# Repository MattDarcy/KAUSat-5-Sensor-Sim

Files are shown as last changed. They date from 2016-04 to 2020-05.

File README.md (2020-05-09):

# KAUSAT-5 Sensor Simulator

**Summary**

MATLAB/Embedded C software for the ADCS sensor simulator for KAUSAT-5, a 3U CubeSat developed at Korea Aerospace University's [Space Systems Research Laboratory](https://www.facebook.com/ssrlmm/). This was the main work of my 2014-2015 Fulbright grant to South Korea. The complete system was capable of delivering real-time simulated sensor data from the MATLAB-STK interface via ATMega128 to KAUSAT-5's ADCS board for on-the-ground debugging purposes.

Simulated sensors included 5x sun, x-y-x mag, and x-y-z gyro. 
Data transfer protocols included UART, SPI, I2C.

**>>> [Check Out On YouTube](https://www.youtube.com/watch?v=KioAFfxGl1A) <<<**

Out Front of KAU (https://www.youtube.com/watch?v=KioAFfxGl1A)

Running simulation of KAUSAT-5 (https://www.youtube.com/watch?v=KioAFfxGl1A)

**Hardware**

ATMega128 (1x as simulator unit, 1x as MASTER for simulator verification)  
LTC2630 Digital-Analog Converter (13x)  
Simulator PCB (1x) created in Altium Designer v13.2
See documentation folder for details

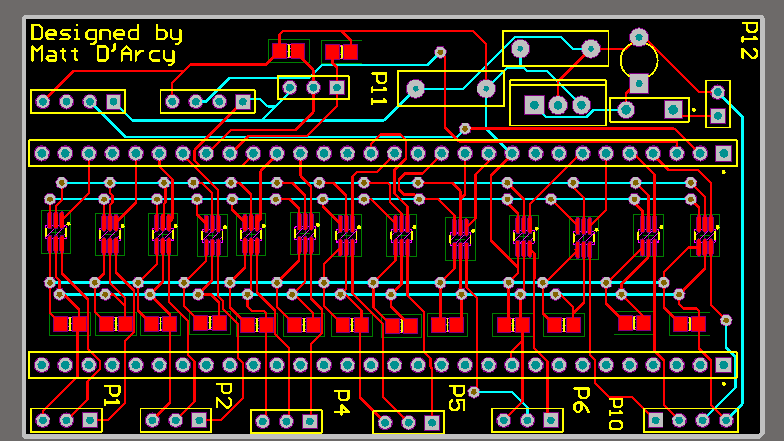
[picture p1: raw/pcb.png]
Simulator PCB

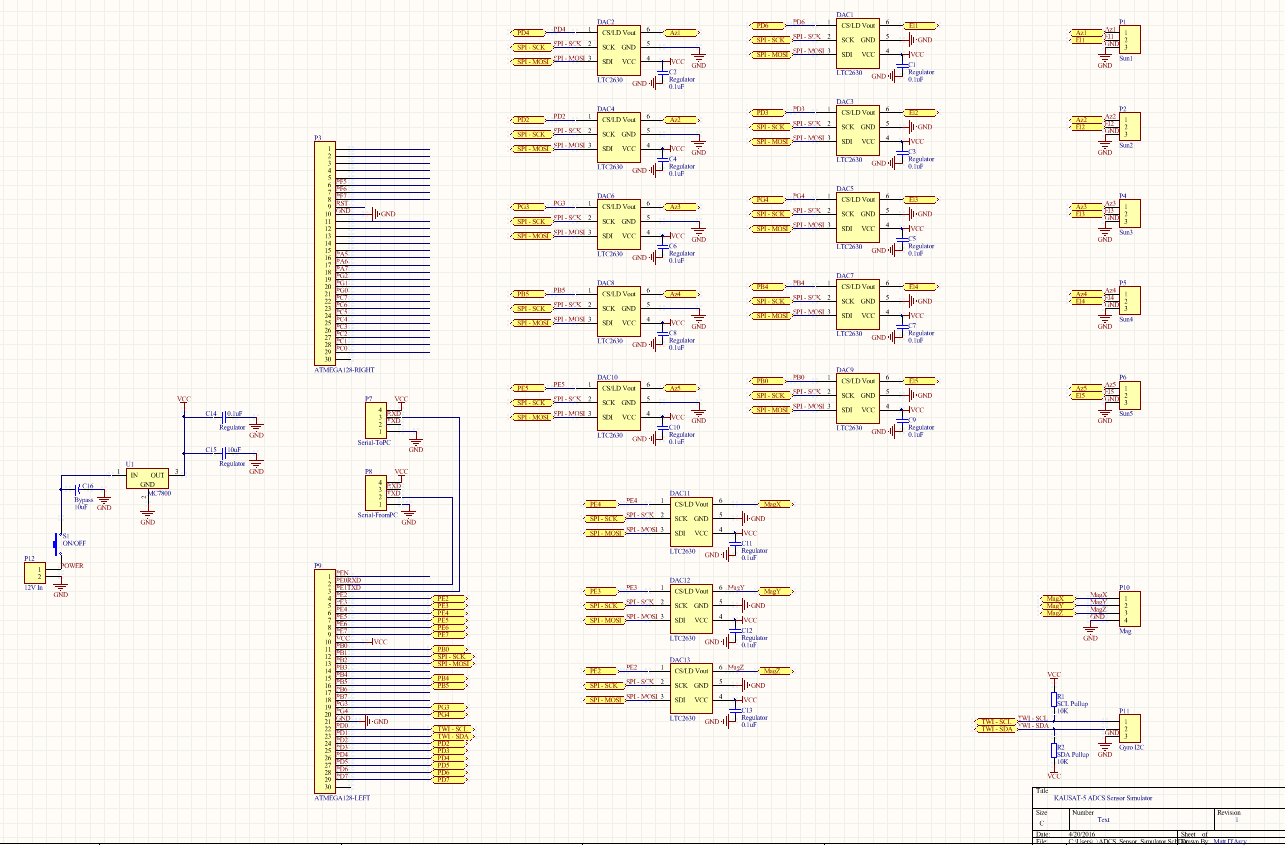
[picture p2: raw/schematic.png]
Simulator Schematic


**Embedded**

Embedded code was compiled with IAR Embedded Workbench IDE v6.7.  
Embedded code divided into MASTER and SLAVE according to TWI scheme.  
System design scheme implies the sensor simulator itself is SLAVE, and verification unit (in this case my pc, but generally KAUSAT-5) is MASTER.

**SLAVE**

To open in IAREW, open Sensor_Simulator.eww in Embedded/SLAVE311  
To see individual .c and .h files, go to Embedded/SLAVE311/standard

**MASTER**

To open in IAREW, open MASTER315.eww in Embedded/MASTER315  
To see individual .c and .h files, go to Embedded/MASTER315

**Final Report**

The material in this repository and final report is my own and does not reflect the stance nor view of the State Department, Fulbright Korea, nor Korea Aerospace University.

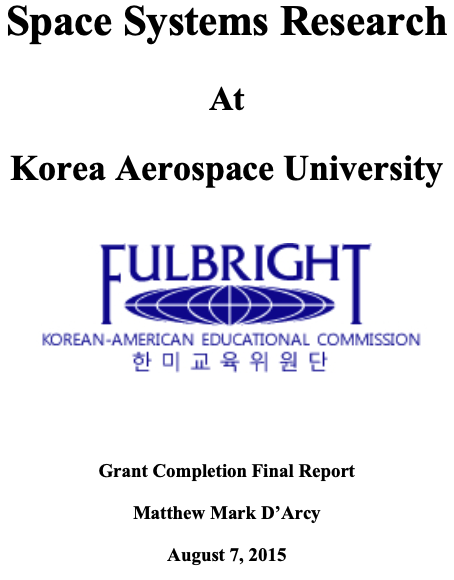
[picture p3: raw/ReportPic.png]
Download Final Report


---

© 2020 [Matt D'Arcy](http://linkedin.mathewdarcy.com), shared under the [MIT License](http://www.opensource.org/licenses/MIT).

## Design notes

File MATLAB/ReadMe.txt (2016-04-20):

# STK-MATLAB Interface

Created with help from this 'STK DIY Series' video: https://vimeo.com/60602502
Also used STK Programming Interface: http://www.agi.com/resources/help/online/stkdevkit/10.1/

MATLAB files:
  
  KAUSAT5_Sensor_Sim2.m
  update_K52.m
  get_attitude_data.m
  get_posvel_data.m
  
STK generated data as text files:

  case1_v.a
  case1_v.e
  
KAUSAT-5 3D model and articulation files for STK:
  
  kausat66.dae
  kausat66.anc
  
#Notes:

    Created with MATLAB 2012B and STK10
    User must have following files and path referenced in code: kausat66.dae model and kausat66.anc articulation files
    User must have additional 3 function files and 2 STK data textfiles included in path.
        
    User must have correct COM port for RS232-ATMEGA128 USART referenced in this file.
    User must hit the 'a' key with the figure as the active screen.

#How it works:
 
    1) A user must use J2Perturbation Propagator in STK, plug in all orbital
    and desired time parameters, mass, area, etc. and create two textfiles
    of attitude and position data. They must referenced by name and path below in
    the code, if not in the path of this code's .m file. Even though the
    position and attitude data from the text files will not be used directly
    in further analyses, all data used in further analyses comes from STK as
    a result of the data from the textfiles that are pumped into STK via
    this code. In other words, STK makes data files, then feeds the data files to MATLAB
    in a separate operation. I have attached sample data files for KAUSAT-5's scenario.
 
    2) This code uses RealTime Propagator to define Kausat5 and its sensors.
    I added some graphics to help see what is going on. It inputs the text 
    file data to STK, and the desired data is given to MATLAB.
    The data desired is:
        -Azimuth and Elevation angles of each sun sensor in +/- radians.
        -X,Y,Z body axes' magnetic intensity in units of +/- nT (nano-Teslas).
        -X,Y,Z body axes' gyro rotation in units of +/- radians per second.
 
    3) A separate function uses a timer to update the data from STK to
    output to the MATLAB command window each second. This function also executes data 
    feeding into STK. The data-feed itself calls upon two other functions
    that also must be in the same path as this file, or added before 
    execution. Those two functions designate the text file data into 
    variables like x_pos, y_pos, q1, q2, etc. to be fed into STK. 
 
#Bugs/WIP 

    1) If you zoom into the 3D satellite model in STK, time slows down...
          Determined to be dependent on PC graphics hardware.
    2) Confined to 10 minute run with MATLAB timer
          Stack overflow couldn't help, if you can fix this please send me a msg :)
    3) There are considerable multi-second chunks of data-less time during
       some runs, while sometimes it runs smoothly. Consider running on a
       workhorse of a pc.

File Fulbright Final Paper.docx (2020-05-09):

Space Systems Research

At

Korea Aerospace University

Grant Completion Final Report

Matthew Mark D’Arcy

August 7, 2015

i.) Abbreviated Terms

ADCS – Attitude Determination and Control Subsystem

ADC-SSS – Attitude Determination and Control Sensor Simulation System

DAC – Digital-Analog Converter

KAU – Korea Aerospace University

KAUSAT-5 – Korea Aerospace University Satellite 5

MATLAB – Matrix Laboratory

SPI – Serial-Peripheral Interface

SSRL – Space Systems Research Laboratory

STK – Systems Toolkit

TWI – Two-Wire Interface

USART – Universal Synchronous/Asynchronous Receiver/Transmitter

I.) Introduction and Alterations in Scope

At the time of my application submittal for the 2014-2015 Fulbright US Student Program in South Korea, I had proposed to join the Space Systems Research Laboratory (SSRL) of Korea Aerospace University (KAU) on the Korea Aerospace University Satellite 5 (KAUSAT-5) project. KAUSAT-5 is the name coined for a 3U CubeSat¹ in development, a cubic form-factor structural bus stacked three times into a single unit, and its mission objectives are to perform infrared observation of the Earth, measure radiation in the ionosphere, demonstrate a fuzzy-logic controller for solar power generation, and demonstrate successful attitude control through actuation of the custom control moment gyroscope.

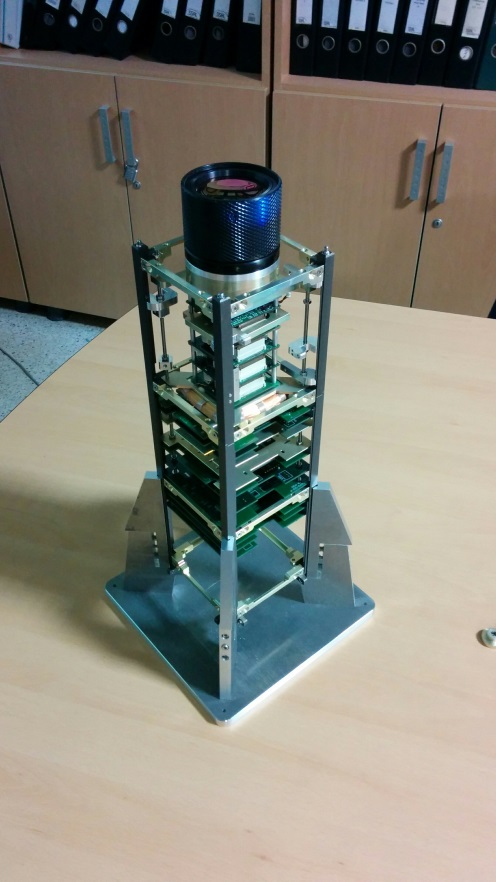
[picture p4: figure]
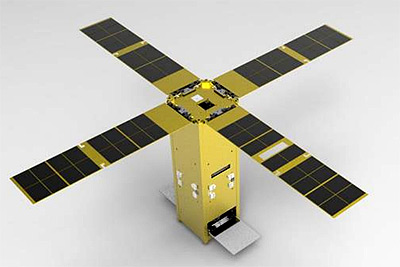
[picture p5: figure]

Figure 1 - KAUSAT-5 Structure w/ Camera (L) and Flight Model 3D Render (R)

KAUSAT-5 was to already have been handed off to the launch service and prepped for a November 2014 insertion into orbit. Therefore, I had initially proposed to carry on with the line of work I had been involved in during my 2012 internship at NASA – Marshall Space Flight Center: mission design. I would have become familiar with the ground station and communication protocol specific to KAUSAT-5, and perform the communications necessary to carry out the mission.

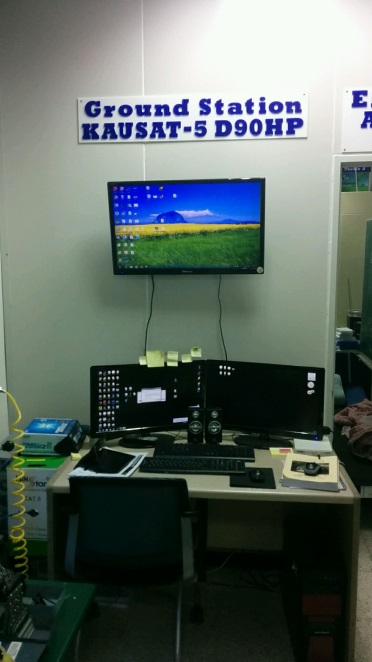
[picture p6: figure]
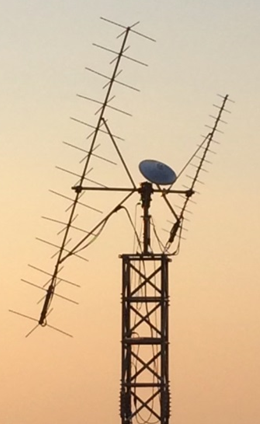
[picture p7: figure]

Figure 2 - SSRL Ground Station Console (L) and Antennae (R)

I would have used the data collected from KAUSAT-5’s mission to run performance and feasibility analyses culminating in the design and proposal of a new academia-scale small spacecraft mission involving multiple CubeSats collaborating in a flying formation, or ‘constellation’, to produce a desired effect. The key strength of this scheme is that multiple smaller, lighter, cheaper spacecraft can produce similar if not better mission results than larger, heavier, expensive spacecraft.

However due to delays on the launch provider’s end, cascading into delays from the students’ end, KAUSAT-5’s engineering test model (the first of two constructs, to be followed by the flight model) had not yet begun. The undergraduate and graduate students involved in the project were still at work designing and customizing the mechanical and electrical components specific to their own subsystems. Due to the delays, it was fitting for me to be involved in the development of the project.

The seven subsystems of KAUSAT-5, each covering a different functionality of the spacecraft, include the Attitude Determination and Control Subsystem (ADCS). A spacecraft’s attitude describes its orientation in space relative to other bodies such as the Earth or the Sun. Attitude determination and control describes the processes by which a spacecraft processes data from various sensors to determine how it is oriented in space, and actuating mechanisms to manipulate its attitude, such as reaction wheels, gyroscopes, and thrusters. A spacecraft’s attitude is important to its mission whenever its sensors or instruments require pointing in a specific direction. Two examples include cameras observing the Earth and solar cells absorbing the sun’s rays.

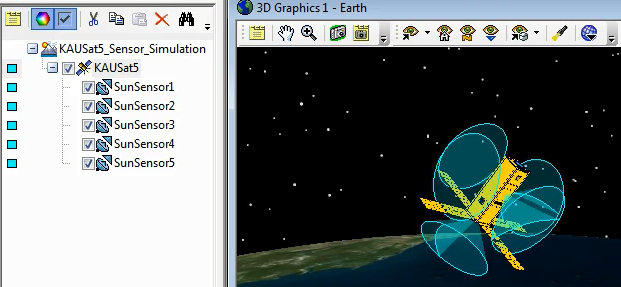
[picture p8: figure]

Figure 3 - KAUSAT-5 w. 5x Sun Sensors and Conical FOV

Though the structural and mechanical subsystem would have been more aligned with my mechanical engineering background, the lab supervisor recommended I go outside of my comfort zone and learn new technical skills on a full concept-to-practice project. I was given the opportunity to be the developer of the KAUSAT-5 Attitude Determination and Control Sensor Simulation System (ADC-SSS).

The ADC-SSS is a concept conceived by the lab’s supervisor some years ago during the planning and design of KAUSAT-5. The purpose of the ADC-SSS is to provide simulated sensor data for KAUSAT-5’s ADCS so the developers can verify the attitude control algorithm with the spacecraft still on the ground. While this verification process is typically performed for large, expensive spacecraft, the trend for lighter, faster, cheaper CubeSats has been to simply code the control algorithm and ship for launch or include a passive system such as a gravity-gradient boom; an appendage extending from the CubeSat that utilizes the difference in gravitational pull on the satellite versus the boom’s tip-mass to orient the spacecraft.

II.) Project Goals

The main project goal was to create a fully-functioning ADC-SSS ready for integration with the KAUSAT-5 ADCS. The system required the transmission of data of five sun sensors, and three-axis magnetic and gyroscope sensors from PC software to a microcontroller and then on to a third microcontroller. The data transmissions needed to maintain integrity and occur once per second.

Secondary project goals included all of the personal study and skills developed during the course of the project.

III.) Methodologies and Timeframe

The ADC-SSS was meant to include several layers of hardware and software to interface with the CubeSat’s ADCS. The configuration can be described by following a packet of data—a group of sensors’ data values at any single moment in time—from creation to delivery to the ADCS.

The entire process starts in a mathematical analysis tool frequently used in engineering applications: Matrix Laboratory (MATLAB). The user is able to code custom programs that enable MATLAB to manipulate other computer software. The Systems Toolkit (STK) software suite allows for visual and statistical analyses of land, air, sea, and spacecraft, and MATLAB was scripted according to the projected launch parameters to create a KAUSAT-5 simulated scenario within STK.

IV.) Outcome and Results

A functional MATLAB-STK code, MASTER/SERVANT embedded C programs, and the simulator box were developed and successfully deliver the desired data to the SERVANT each second during the simulation system’s operation. The system was handed off to the ADCS engineers to continue development of KAUSAT-5’s control algorithm.

V.) Affiliate Support

The Space Systems Research Laboratory of Korea Aerospace University is directed by Dr. Young-Keun Chang, an expert in satellite technology and an active member of the international space community. During the Fulbright application phase, I exchanged communications with Dr. Chang regarding the current activities in the lab and alternatives to KAUSAT-5 should the project have suffered cancellation. Other projects included software simulations and analyses of satellite constellations and a small satellite conceptual design software tool.

After expressing my interest in the CubeSat project, Dr. Chang granted me a letter of affiliation offering participation, securement of dormitory accommodations, links to student organizations of interest including KAU’s ballooning, paragliding, and gliding clubs, and involvement in KAUSAT-5’s launch campaign.

Dr. Chang also runs the Global Surveillance Research Center and contracts with the Korean military for space-related projects. The result is that generally Dr. Chang can only dedicate Saturday mornings to his lab students, and so throughout the first half of the year I attended Saturday meetings to better acquaint myself with Dr. Chang and some of the material he taught. The lab tradition is to attend lunch meetings during these days to discuss various topics from Korean culture to Dr. Chang’s life in Korea as well as his study in the US.

Throughout the year, I was able to utilize the campus’ dining hall, which served healthy and enjoyable meals at a reduced price, generally 2,000-3,000 KRW. This made a humongous difference in my spending and I was able to live comfortable during the year in Korea.

The Hwajeon-dong community service center is located a fifteen minute walk from campus and the lab supervisor helped me sign up for a membership to the health club in its basement. However, from December onward I was able to sign up to use the health club located in the basement of the dormitory, a three minute walk from the lab.

While researching at KAU, I was not registered with the university, and had no student ID card. The dormitory staff heard my case and permitted me to enter to utilize the health club at cost, cafeteria, and convenience store when requested. Lab colleagues were generous to have me accompany them into the university library and borrow books on their credentials when needed, such as the C programming materials. Access was granted to a spacious window-side desk, wired/WiFi internet, books, software, and electrical components necessary to develop the project. Materials that were not readily available in the lab were purchased and given to me through utilization of the lab’s budget. In the event of design errors and rendering of materials as useless, I purchased updated materials at my own expense. The lab budget also funded my travel to a conference in Jeju, and equipment tests in Daejeon.

The graduate students in the lab each possessed different areas of expertise within the scope of satellite development, and usually had solutions to my problems when inquired. The lab supervisor served as my mentor day to day and checked my progress, offered aid in solving unexpected software and electrical errors, and guided the project phases from tutorial tasks to project completion. As a result of my time in the lab, I have built up a good relationship with the lab supervisor, and as of the submittal of this report we are discussing avenues through which I may return to Korea for my next step.

VI.) Project Reflection

Due to the volatile nature of the space industry, which does not exclude space academia, I did not view my research project in Korea as developing a part of KAUSAT-5 but rather as an immersion experience into Korean culture and academia while playing a technical role of the space systems variety.

Upon my arrival at SSRL the supervisor inquired as to which subsystem I would like to be a part of. I had initially intended to approach the project from a systems engineering perspective, knowing limited information about all subsystems and the overall construct as opposed to specializing. However, after some discussion with the supervisor we reached a mutual agreement that both parties would benefit more from my assignment not only to a specific subsystem but within a new technical area involving a complete project that I would pursue alone.

From my perspective, the appropriateness of this path stemmed from past experiences and future prospects. In the past, I had lacked software and electrical experience entirely, and had even been told in interview feedback that it was so. Additionally, this project was the pursuance of a new technology, which the reduction to practice of would be valuable in application processes for future employment, graduate programs, as well as funding opportunities.

I struggled for several weeks simply because I was trying to run Windows 7 and a lot of heavy software packages on a laptop that came with Windows 8. I needed to re-install Windows several times in order to finally get all of the software packages to function correctly. In the future, building a strong desktop PC is necessary in a laboratory setting. I also learned that when programming, it is beneficial to use a Linux-based system like Ubuntu or Mac OS because many computer programming packages simply work after installation, as opposed to issues that take sometimes multiple days to resolve for Windows users. The software at the lab was Windows-based, but this is something to consider for the future.

Once the software was operational, I began studying STK. I went through two manuals of tutorials to familiarize myself with its protocol, language, and specific data extraction.

Upon completion, I went through a complete manual on C Programming. This was the first time I had approached computer programming in a setting other than a basic engineering course, yet the easy-to-digest explanations brought me through even the most complex topic in the C language with some ease: pointers. I completed the example problems as I read, and was ready to begin simple programming tutorials after three weeks.

For the rest of the year, I was working with two Atmel ATMega128a microcontrollers and peripheral components such as digital-analog-converter (DAC) chips. The ATMega128a datasheet guided me through hardware specifics such as characterizing pins and internal registers. The supervisor started a circuit of simple microcontroller actions such as blinking an LED, rotating a motor, controlling the speed of a motor, and using a switch to perform the previous actuations. With the basic C and embedded programming experience, it was time to begin design of the ADC-SSS.

The data required for KAUSAT-5’s ADC-SSS was dependent on the sensors included in the spacecraft. KAUSAT-5’s design features sun, magnetic, and gyroscope sensors. The sun sensors are placed on five of the six surfaces of the spacecraft and work synchronously to determine the spacecraft’s orientation to the sun. The magnetic sensors measure the X, Y, and Z vectors of Earth’s magnetic field and compare them with the X, Y, and Z vectors of the spacecraft. The gyroscope sensors measure the rotation rate of the satellite in the X, Y, and Z axes during a tumbling scenario. After setting up KAUSAT-5 within STK, defining the 3D Model and orbit characteristics, it was possible to manipulate STK to calculate and export data corresponding to KAUSAT-5’s sensors.

I first needed to program MATLAB to autonomously setup the same KAUSAT-5 orbit scenario, define the sensors, and extract the desired sensor data with each push of a button. The difficulty of this portion of the project was rooted in the fact that the resources online for the MATLAB-STK interface were very limited. I had one YouTube lecture and an unreliable command dictionary to work with, from which I reverse-engineered the script.

MATLAB would take the data from the simulation’s sensors and export it through a universal synchronous/asynchronous receiver/transmitter (USART). The USART converted the data to electrical signals that the individual pins of the microcontroller could read and decipher within the chip.

The microcontroller receiving the data initially was the brain of the simulator box. This microcontroller was also termed the “MASTER” because it was responsible for driving the data in the form of electrical signals to the second “SERVANT” microcontroller. Within the MASTER, the data needed to be processed and sent to the SERVANT through data transmission schemes that included serial-peripheral interface (SPI) and two-wire interface (TWI).

SPI utilizes DAC chips to convert digital values, namely numbers, into analog electrical voltages that can be interpreted by a potentiometer. Such a device is expected to be present in the ADCS and so anything beyond the DAC outputs was outside of the scope of the ADC-SSS.

TWI transmits data through two wires by timing electrical signal pulses, comparable to a Morse code of voltages instead of taps. From my experience in developing the ADC-SSS, TWI is a very timing-intensive operation and caused the most errors throughout the year. Throughout several instances I would find the SERVANT receiving gibberish data, or intermittently failing proper data communication with no indicators of repeatability in the rate of failures.

My approach to fixing these errors was to completely transcribe the ATMega128a data sheet’s section on TWI into my own words twice over, analyzing diagrams and developing a timeline describing how the bits of each register were set (or became set) at each phase in the data transfer, and performing step-by-step register analyses on failure scenarios to get a better understanding of the bug in the microsecond-scale operation.

Toward the beginning of my involvement in the lab, it was difficult to gauge the appropriate work-life balance. Other lab members put in six days of work weekly, lived at the lab, and often worked up to twenty hours daily. For the first several months, I deemed it appropriate to attempt to assimilate and so I worked anywhere from 10 to 12 hours per day and six days per week at the lab. While this helped me learn the material and begin development quickly, it established an awkward feeling for getting out of the lab and socializing and networking. Through observation and conversation with lab members, I determined that the long work hours were not so much because they had work to do, but because the lab culture induced both external and internal pressure on the students. I often would find students at their desks sleeping, playing games, or shopping online. All of this, along with project delays, led me to speak up to the supervisor inquiring about the work schedule scheme. I approached the situation diplomatically as my purpose at SSRL was not to change management, but I voiced my opinion on behalf of other lab members about the notions of a healthy work-life balance and work efficiency. By the springtime, lab members who used to live in the lab were able to move into the dormitory and others began exercising at the health club. While having a firm resolve about this situation earlier on would have proved more rewarding for both my and my colleagues’ experiences, it took some time to accurately assess the environment and progress along a reasonable course of action.

VII.) Bibliography

CubeSat. “CubeSat.” CubeSat. August 7, 2015. cubesat.org.

VIII.) Biography

A New Jersey native, Matt grew up between Stratford and Cherry Hill. A large portion of Matt’s childhood was spent at his grandparents’ home where his imagination was free to expand. Matt’s grandfather frequently spoke to him about a career as a Drexel University graduate and electrical engineer during the Apollo missions. Matt became interested in engineering and space exploration through these conversations. While attending Cherry Hill High School West, Matt was particularly intrigued by Instructor Scott Sweeten’s planetary exploration course, which influenced his involvement in the Drexel Space Systems Laboratory.

At Drexel, Matt worked with Korea Aerospace University alumnus Dr. Jin Kang, who was the main influence in Matt’s decision to pursue a Fulbright application to South Korea. In 2014, he graduated with a Bachelor of Science in Mechanical Engineering and Mechanics from Drexel University in Philadelphia. Immediately upon graduation, he joined his fellow Korean Critical Language Scholarship recipients and studied in Wonju, Gangwon-do until commencing research on satellite systems at the Space Systems Research Laboratory of Korea Aerospace University. Matt was the main developer of the attitude determination and control sensor simulation system for a 3U CubeSat – KAUSAT-5. When Matt is not debugging errors, he is involved in outdoor activities, fitness, mobile and web development, networking, travel and rewards profiles, and other space topics.

1. CubeSat, “CubeSat,” CubeSat, August 7, 2015, cubesat.org.

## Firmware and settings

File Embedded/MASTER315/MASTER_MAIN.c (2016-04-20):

/*****************************************************************************
*
* Atmel Corporation
*
* File              : main.c
* Compiler          : IAR EWAAVR 2.28a/3.10c
* Revision          : $Revision: 1.13 $
* Date              : $Date: 24. mai 2004 11:31:20 $
* Updated by        : $Author: ltwa $
*
* Support mail      : avr@atmel.com
*
* Supported devices : All devices with a TWI module can be used.
*                     The example is written for the ATmega16
*
* AppNote           : AVR315 - TWI Master Implementation
*
* Description       : Example of how to use the driver for TWI master 
*                     communication.
*                     This code reads PORTD and sends the status to the TWI slave.
*                     Then it reads data from the slave and puts the data on PORTB.
*                     To run the example use STK500 and connect PORTB to the LEDS,
*                     and PORTD to the switches. .
*
****************************************************************************/


/****************************************************************************
MASTER_MAIN.c
Refactored for KAUSAT-5 Sensor Simulator
Refactored by Matt D'Arcy. 
****************************************************************************/


#include <ioavr.h>                                                                                              //Redundant, already in TWI_Master.c
#include <inavr.h>                                                                                              //Redundant, already in TWI_Master.c  
//#include "MASTER_TWI.h"   
#include <stdio.h>
#include "MASTER_TWI.c"                                                                                         //Include all the things



// ADCS BOARD CALLS
// ADCS Board will send over 2 bytes and depending on what it is, the slave (simulator) needs to send out the corresponding data byte (one half of a data reading)
// Via the data line on I2C
#define MPU6050_RA_GYRO_XOUT_H      0x43
#define MPU6050_RA_GYRO_XOUT_L      0x44
#define MPU6050_RA_GYRO_YOUT_H      0x45
#define MPU6050_RA_GYRO_YOUT_L      0x46
#define MPU6050_RA_GYRO_ZOUT_H      0x47
#define MPU6050_RA_GYRO_ZOUT_L      0x48


#define TWI_GEN_CALL         0x00  // The General Call address is 0                                             //General Call is 0 BUT TWAR must then by 0x01 to enable such a call

// Sample TWI transmission commands
#define TWI_CMD_MASTER_WRITE 0x10                                                                               //Seems to be random number 0001 0000
#define TWI_CMD_MASTER_READ  0x20                                                                               //Seems to be random number 0010 0000

// Sample TWI transmission states, used in the main application.
#define SEND_DATA             0x01                                                                              //Seems to be random number 0000 0001
#define REQUEST_DATA          0x02                                                                              //Seems to be random number 0000 0010
#define READ_DATA_FROM_BUFFER 0x03                                                                              //Seems to be random number 0000 0011


unsigned char j = 0x43;
unsigned int last_packet[48] = {0,0,0,0,0,0,0,0, //48 from 0 to 47...GyroxHi
			         0,0,0,0,0,0,0,0, //GyroxLo
			         0,0,0,0,0,0,0,0, //GyroyHi
			         0,0,0,0,0,0,0,0, //GyroyLo
			         0,0,0,0,0,0,0,0, //GyrozHi
			         0,0,0,0,0,0,0,0}; //GyrozLo
unsigned int new_packet[48] = {1,1,1,1,1,1,1,1, //48 from 0 to 47...GyroxHi
			        1,1,1,1,1,1,1,1, //GyroxLo
			        1,1,1,1,1,1,1,1, //GyroyHi
			        1,1,1,1,1,1,1,1, //GyroyLo
			        1,1,1,1,1,1,1,1, //GyrozHi
			        1,1,1,1,1,1,1,1}; //GyrozLo
unsigned int is_new_packet = 1;
unsigned int temp = 0;
unsigned int gyroxhi,gyroxlo,gyroyhi,gyroylo,gyrozhi,gyrozlo;
unsigned int last_byte_requested;

void init_UART(void) //Set desired registers according to the ATMEGA128 Datasheet
{
    DDRE = 0xFB; //1111 1000
    UCSR0A = 0x00;
    UCSR0B = (1<<RXEN0)|(1<<TXEN0)|(1<<RXCIE0);//0x98;
    UCSR0C = (1<<UCSZ01)|(1<<UCSZ00); 
    UBRR0H = 0x00; //set baud rate hi
    UBRR0L = 0x03; //set baud rate lo
    
 
  
  //DDRE=0xfe; //pe1-tx, pe0-rx
    //DDRD = 0xFB; //1111 1011
    //UCSR1A = 0x00;
    //UCSR1B = (1<<RXEN1)|(1<<TXEN1)|(1<<RXCIE1);//0x98;
   // UCSR1C = (1<<UCSZ11)|(1<<UCSZ10); 
    //UBRR1H = 0x00; //set baud rate hi
   // UBRR1L = 103; //set baud rate lo
}


int putchar(int data_zigbee)//Copy packet for processing, "clean the mailbox" for a new packet being delivered later
{
  while (((UCSR0A >> 5) & 0x01) == 0) // while UDRE data register is empty
            ;  //Do nothing
  UDR0 = data_zigbee; //When not empty, set UDR1 to the data packet
  UCSR0A |= 0x20; //set UCSR1A (USART Control and Status Register 1 for Port A) to 0010 0000, default is 0010 0000, as in the data register is empty!
                  //In other words, imagine you have a mailbox where only 1 packet can go at a time. You copied the delivered packet and sent it to processing in the house, but you need to clean out the original packet
                  //from the data register
  return data_zigbee; //send that copied packet to be processed. Returns to the interrupt.
}


unsigned char TWI_Act_On_Failure_In_Last_Transmission ( unsigned char TWIerrorMsg )
{                                                                                                               //TWIerrorMsg = TWI_Get_State_Info( ) which returns the variable TWI_state, which commonly refers
                                                                                                                //to TWSR except for when setting to 0xF8 RIGHT before a transmission from master to slave
                    // A failure has occurred, use TWIerrorMsg to determine the nature of the failure
                    // and take appropriate actions.
                    // Se header file for a list of possible failures messages.
                    
                    // Here is a simple sample, where if received a NACK on the slave address,
                    // then a retransmission will be initiated.
 
  if ( (TWIerrorMsg == TWI_MTX_ADR_NACK) | (TWIerrorMsg == TWI_MRX_ADR_NACK) )                                  //If the TWSR code is such that master received a NACK from slave after address
    TWI_Start_Transceiver();                                                                                    //Start transceiver (assumes data is already loaded in buffer and do repeated start)
    
  return TWIerrorMsg;                                                                                           //return the status code
}

void main(void)
{
  // This example code runs forever; sends a byte to the slave, then requests a byte
  // from the slave and stores it on PORTB, and starts over again. Since it is interupt
  // driven one can do other operations while waiting for the transceiver to complete.
  init_UART();
  printf("");
  unsigned char messageBuf[4];                                                                                  //messageBuf is 4 so 3 characters are useable 0, 1, and 2
  unsigned char TWI_targetSlaveAddress, temp, TWI_operation=0,                                                  //more unsigned chars for use later
                pressedButton, myCounter=0;
  //LED feedback port - connect port B to the STK500 LEDS                                                       //can use LEDS connect to port B
  DDRB  = 0xFF;
  PORTB = myCounter;
  //Switch port - connect portD to the STK500 switches
  DDRD  = 0x00;
  TWI_Master_Initialise();                                                                                      //initialize as per TWI_Master.c.....Bitrate, flood TWDR with 1's, enable TWI
  __enable_interrupt();                                                                                         //enable interrupts in general for the ATMEGA128
  TWI_targetSlaveAddress   = 0x10;     
  TWI_operation = REQUEST_DATA; // Set the next operation
  // Send initial data to slave. If not, output becomes eeeeeeeeeeeeeeeeeeeeeee
  messageBuf[0] = (TWI_targetSlaveAddress<<TWI_ADR_BITS) | (FALSE<<TWI_READ_BIT);
  messageBuf[1] = j;
  TWI_Start_Transceiver_With_Data( messageBuf, 2 );
  ms_delay(10); //NECESSARY OR THE SERIAL OUTPUT GETS MESSED UP
  printf("Sent 0x%X\n\r",messageBuf[1]);
  //In this time the slave receives the data from the buffer, operates it (+1) and puts in back in the buffer. 
  //Extracting this new data in buffer, printf'ing it, and then sending it back is the next step.
  
  for (;;)
  {
    
    j = 0x43;
    do 
    {
        //printf("j is 0x%X\n\r",j);
        // Check if the TWI Transceiver has completed an operation.
        if (!TWI_Transceiver_Busy()){
            // Check if the last operation was successful
            if (TWI_statusReg.lastTransOK){
                // Determine what action to take now
                if (TWI_operation == SEND_DATA){
                    // Send data to slave
                    messageBuf[0] = (TWI_targetSlaveAddress<<TWI_ADR_BITS) | (FALSE<<TWI_READ_BIT);
                    messageBuf[1] = j;
                    TWI_Start_Transceiver_With_Data( messageBuf, 2 );
                    ms_delay(10); //NECESSARY OR THE SERIAL OUTPUT GETS MESSED UP
                    //printf("Sent 0x%X\n\r",messageBuf[1]);
                    last_byte_requested = j;
                    TWI_operation = REQUEST_DATA; // Set next operation
                    }
                if (TWI_operation == REQUEST_DATA){
                    // Request data from slave
                    messageBuf[0] = (TWI_targetSlaveAddress<<TWI_ADR_BITS) | (TRUE<<TWI_READ_BIT);
                    TWI_Start_Transceiver_With_Data( messageBuf, 2 );
                    TWI_operation = READ_DATA_FROM_BUFFER; // Set next operation        
                    }
                if (TWI_operation == READ_DATA_FROM_BUFFER){
                    // Get the received data from the transceiver buffer
                    TWI_Get_Data_From_Transceiver( messageBuf, 2 );
                    PORTB = messageBuf[1];        // Store data on PORTB.
                    //printf("Received 0x%X\n\n\r",PORTB);
                    switch(j){
                        case MPU6050_RA_GYRO_XOUT_H:
                          gyroxhi = PORTB;
                          new_packet[0] = PORTB_Bit7;
                          new_packet[1] = PORTB_Bit6;
						  new_packet[2] = PORTB_Bit5;
						  new_packet[3] = PORTB_Bit4;
						  new_packet[4] = PORTB_Bit3;
						  new_packet[5] = PORTB_Bit2;
						  new_packet[6] = PORTB_Bit1;
						  new_packet[7] = PORTB_Bit0;
                        case MPU6050_RA_GYRO_XOUT_L:
                          gyroxlo = PORTB;
                          new_packet[8] = PORTB_Bit7;
                          new_packet[9] = PORTB_Bit6;
						  new_packet[10] = PORTB_Bit5;
						  new_packet[11] = PORTB_Bit4;
						  new_packet[12] = PORTB_Bit3;
						  new_packet[13] = PORTB_Bit2;
						  new_packet[14] = PORTB_Bit1;
						  new_packet[15] = PORTB_Bit0;
                        case MPU6050_RA_GYRO_YOUT_H:
                          gyroyhi = PORTB;
                          new_packet[16] = PORTB_Bit7;
                          new_packet[17] = PORTB_Bit6;
						  new_packet[18] = PORTB_Bit5;
						  new_packet[19] = PORTB_Bit4;
						  new_packet[20] = PORTB_Bit3;
						  new_packet[21] = PORTB_Bit2;
						  new_packet[22] = PORTB_Bit1;
						  new_packet[23] = PORTB_Bit0;
                        case MPU6050_RA_GYRO_YOUT_L:
                          gyroylo = PORTB;
                          new_packet[24] = PORTB_Bit7;
                          new_packet[25] = PORTB_Bit6;
						  new_packet[26] = PORTB_Bit5;
						  new_packet[27] = PORTB_Bit4;
						  new_packet[28] = PORTB_Bit3;
						  new_packet[29] = PORTB_Bit2;
						  new_packet[30] = PORTB_Bit1;
						  new_packet[31] = PORTB_Bit0;
                        case MPU6050_RA_GYRO_ZOUT_H:
                          gyrozhi = PORTB;
                          new_packet[32] = PORTB_Bit7;
                          new_packet[33] = PORTB_Bit6;
						  new_packet[34] = PORTB_Bit5;
						  new_packet[35] = PORTB_Bit4;
						  new_packet[36] = PORTB_Bit3;
						  new_packet[37] = PORTB_Bit2;
						  new_packet[38] = PORTB_Bit1;
						  new_packet[39] = PORTB_Bit0;
                        case MPU6050_RA_GYRO_ZOUT_L: 
                          gyrozlo = PORTB;
                          new_packet[40] = PORTB_Bit7;
                          new_packet[41] = PORTB_Bit6;
						  new_packet[42] = PORTB_Bit5;
						  new_packet[43] = PORTB_Bit4;
						  new_packet[44] = PORTB_Bit3;
						  new_packet[45] = PORTB_Bit2;
						  new_packet[46] = PORTB_Bit1;
						  new_packet[47] = PORTB_Bit0;
                        }
                    TWI_operation = SEND_DATA;    // Set next operation        
                    }
            }
            else{ // Got an error during the last transmission
                // Use TWI status information to detemine cause of failure and take appropriate actions. 
                TWI_Act_On_Failure_In_Last_Transmission( TWI_Get_State_Info( ) );
                } 
            }
        j++;
        } while(j<0x49);
		//printf("Before the if statement\n\r");
        //printf("The new bits are %d%d%d%d%d%d%d%d\n\r",new_packet[0],new_packet[1],new_packet[2],new_packet[3],new_packet[4],new_packet[5],new_packet[6],new_packet[7]);
		//printf("The old bits are %d%d%d%d%d%d%d%d\n\r",last_packet[0],last_packet[1],last_packet[2],last_packet[3],last_packet[4],last_packet[5],last_packet[6],last_packet[7]);
        if((memcmp(new_packet,last_packet,sizeof(new_packet)) != 0) && j == 0x49){
        //printf("In the if statement\n\r");
        //printf("The new bits are %d%d%d%d%d%d%d%d\n\r",new_packet[0],new_packet[1],new_packet[2],new_packet[3],new_packet[4],new_packet[5],new_packet[6],new_packet[7]);
		//printf("The old bits are %d%d%d%d%d%d%d%d\n\r",last_packet[0],last_packet[1],last_packet[2],last_packet[3],last_packet[4],last_packet[5],last_packet[6],last_packet[7]);
			is_new_packet = 1;
			memcpy(last_packet,new_packet, sizeof(last_packet));
        }
  		//Initialize 2 arrays. new_packet as all 00000's, last_packet as all 111111's.
  		//In the interrupt, gather each 6 byte transmission into new_packet. 
  		//if arrays are unequal, set boolean to 1. copy new_packet into last_packet.
  		//The packets are now equal but the flag was set to 1 and the printf should occur in the main loop and immediately set the boolean to 0.
  		//printf("The new bits are %d%d%d%d%d%d%d%d\n\r",new_packet[0],new_packet[1],new_packet[2],new_packet[3],new_packet[4],new_packet[5],new_packet[6],new_packet[7]);
		//printf("The old bits are %d%d%d%d%d%d%d%d\n\r",last_packet[0],last_packet[1],last_packet[2],last_packet[3],last_packet[4],last_packet[5],last_packet[6],last_packet[7]);
  		if (is_new_packet == 1){
  			printf("GYRO X = 0x%X%X\n\rGYRO Y = 0x%X%X\n\rGYRO Z = 0x%X%X\n\n\r",gyroxhi,gyroxlo,gyroyhi,gyroylo,gyrozhi,gyrozlo);
  			is_new_packet = 0;
  		}
  }
}
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

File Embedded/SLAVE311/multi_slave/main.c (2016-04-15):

/*****************************************************************************
*
* Atmel Corporation
*
* File              : main.c
* Compiler          : IAR EWAAVR 2.28a/3.10c
* Revision          : $Revision: 1.1 $
* Date              : $Date: Friday, October 15, 2004 11:06:56 UTC $
* Updated by        : $Author: ltwa $
*
* Support mail      : avr@atmel.com
*
* Supported devices : All devices with a TWI module the has a slave address mask
*                     register. The example is written for the ATmega48.
*
* AppNote           : AVR311 - TWI Slave Implementation
*
* Description       : Example of how to use the driver for TWI slave 
*                     communication. This version utilises the address mask register
*                     to enable response on several TWI slave addresses.
*
****************************************************************************/

#include <ioavr.h>
#include <inavr.h>
#include "TWI_Slave.h"

// Sample TWI transmission commands
#define TWI_CMD_MASTER_WRITE 0x10
#define TWI_CMD_MASTER_READ  0x20

unsigned char TWI_Act_On_Failure_In_Last_Transmission ( unsigned char TWIerrorMsg )
{
                    // A failure has occurred, use TWIerrorMsg to determine the nature of the failure
                    // and take appropriate actions.
                    // Se header file for a list of possible failures messages.
  
                    // This very simple example puts the error code on PORTB and restarts the transceiver with
                    // all the same data in the transmission buffers.
  PORTB = TWIerrorMsg;
  TWI_Start_Transceiver();
                    
  return TWIerrorMsg; 
}

void main( void )
{
  unsigned char messageBuf[4];
  unsigned char TWI_slaveAddress, TWI_slaveAddress2, TWI_slaveAddressMask, temp;

  // LED feedback port - connect port B to the STK500 LEDS
  DDRB  = 0xFF; // Set to ouput
  PORTB = 0x55; // Startup pattern

  // Own TWI slave address
  TWI_slaveAddress     = (0x10<<TWI_ADR_BITS);
  TWI_slaveAddress2    = (0x11<<TWI_ADR_BITS);                  // Alternativ slave address to respond to.
  TWI_slaveAddressMask = TWI_slaveAddress ^ TWI_slaveAddress2;  // XOR the addresses to get the address mask.

  // Initialise TWI module for slave operation. Include address and/or enable General Call.
  TWI_Slave_Initialise( TWI_slaveAddress | (TRUE<<TWI_GEN_BIT), TWI_slaveAddressMask); 
                                                                                  
  __enable_interrupt();

  // Start the TWI transceiver to enable reseption of the first command from the TWI Master.
  TWI_Start_Transceiver();

  // This example is made to work together with the AVR315 TWI Master application note. In adition to connecting the TWI
  // pins, also connect PORTB to the LEDS. The code reads a message as a TWI slave and acts according to if it is a 
  // general call, or an address call. If it is an address call, then the first byte is considered a command byte and
  // it then responds differently according to the commands.

  // This loop runs forever. If the TWI is busy the execution will just continue doing other operations.
  for(;;)
  {    
    // Check if the TWI Transceiver has completed an operation.
    if ( ! TWI_Transceiver_Busy() )                              
    {
    // Check if the last operation was successful
      if ( TWI_statusReg.lastTransOK )
      {
    // Check if the last operation was a reception
        if ( TWI_statusReg.RxDataInBuf )
        {
          TWI_Get_Data_From_Transceiver(messageBuf, 3);         
    // Check if the last operation was a reception as General Call        
          if ( TWI_statusReg.genAddressCall )
          {
          // Put data received out to PORTB as an example.        
            PORTB = messageBuf[1];                              
          }
    // Ends up here if the last operation was a reception as Slave Address Match                  
          else
          {
    // Take action dependant on what slave address that was used in the message
            if (messageBuf[0] == TWI_slaveAddress)
            {
    // Example of how to interpret a command and respond.            
            // TWI_CMD_MASTER_WRITE stores the data to PORTB
              if (messageBuf[1] == TWI_CMD_MASTER_WRITE)
                PORTB = messageBuf[2];                            
            // TWI_CMD_MASTER_READ prepares the data from PINB in the transceiver buffer for the TWI master to fetch.
              if (messageBuf[1] == TWI_CMD_MASTER_READ)
              {
                messageBuf[0] = PINB;                             
                TWI_Start_Transceiver_With_Data( messageBuf, 1 );           
              }
            }
            else
            {
              PORTB = messageBuf[1];  // Put TWI address data on PORTB
            }
          }
        }
    // Ends up here if the last operation was a transmission                  
        else
        {
            __no_operation(); // Put own code here.
        }
    // Check if the TWI Transceiver has already been started.
    // If not then restart it to prepare it for new receptions.             
        if ( ! TWI_Transceiver_Busy() )
        {
          TWI_Start_Transceiver();
        }      
      }
    // Ends up here if the last operation completed unsuccessfully
      else
      {
        TWI_Act_On_Failure_In_Last_Transmission( TWI_Get_State_Info() );
      }
      
    }
    // Do something else while waiting for the TWI transceiver to complete.    
    __no_operation(); // Put own code here.
  }
}


/*  
  // A simplified example.
  // This will store data received on PORTB, and increment it before sending it back.

  TWI_Start_Transceiver( );    
         
  for(;;)
  {
    if ( ! TWI_Transceiver_Busy() )                              
    {
      if ( TWI_statusReg.RxDataInBuf )
      {
        TWI_Get_Data_From_Transceiver(&temp, 1);  
        PORTB = temp;
      }
      temp = PORTB + 1;
      TWI_Start_Transceiver_With_Data(&temp, 1); 
    }
    __no_operation();   // Do something else while waiting
  }
}

*/
